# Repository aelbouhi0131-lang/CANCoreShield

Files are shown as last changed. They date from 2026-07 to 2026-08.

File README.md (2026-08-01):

<div align="center">

# CANCore Shield

A professional **Arduino UNO CAN-Bus Shield** designed in **Altium Designer**, featuring CAN communication, microSD storage, power management, and hardware improvements over existing open-source designs.










---

Designed by **Ayoub ELBOUHI**

Electrical Engineering & Embedded Systems Student

ENSA Marrakech

</div>

---

# Overview

CANCore Shield is a compact **Arduino UNO expansion board** developed for **CAN-Bus communication** and **embedded system applications**.

The project was inspired by existing open-hardware CAN shields (including the Seeed Studio CAN-BUS Shield) but redesigned from scratch with several improvements focused on:

- Hardware reliability
- Power management
- SD card compatibility
- PCB organization
- Ease of debugging
- Manufacturing readiness

The entire project was designed using **Altium Designer**, following professional PCB design practices and successfully verified with **0 Design Rule Check (DRC) errors**.

---

# Key Features

- Arduino UNO Shield Form Factor
- MCP2515 CAN Controller
- TJA1050 CAN Transceiver
- SPI microSD Card Interface
- Bidirectional Logic Level Translator
- Dedicated Power Management Circuit
- ON/OFF Power Switch
- Power & Status LEDs
- Optimized Ground Planes
- Two-Layer PCB
- STEP 3D Model Included
- Manufacturing Ready
- Fully DRC Verified

---

# Design Improvements

Unlike the reference open-source designs, this project introduces several hardware enhancements.

## Power Management

A dedicated **ON/OFF switch** allows complete control of the shield power without unplugging the Arduino board.

Benefits:

- Easier testing
- Faster debugging
- Better user experience

---

## Safer microSD Interface

A **unidirectional logic level translator** was added between the Arduino (5V) and the microSD card (3.3V).

Benefits:

- Protects the SD card
- Improves compatibility
- Reliable SPI communication
- Safe voltage conversion

---

## Visual Status Indicators

Dedicated LEDs provide immediate visual feedback regarding board operation.

Useful for:

- Power verification
- Debugging
- Development

---

## PCB Layout Optimization

The PCB was completely redesigned instead of copying an existing layout.

Improvements include:

- Cleaner routing
- Better component placement
- Optimized SPI routing
- Improved CAN signal organization
- Large continuous ground pours
- Easier maintenance

---

## Manufacturing Ready

The board has been fully verified using Altium Designer DRC.

Included manufacturing outputs:

- Gerber Files
- NC Drill Files
- STEP Mechanical Model

Ready for fabrication using:

- JLCPCB
- PCBWay
- Seeed Fusion
- Aisler

---

# PCB Preview

## Top Layer

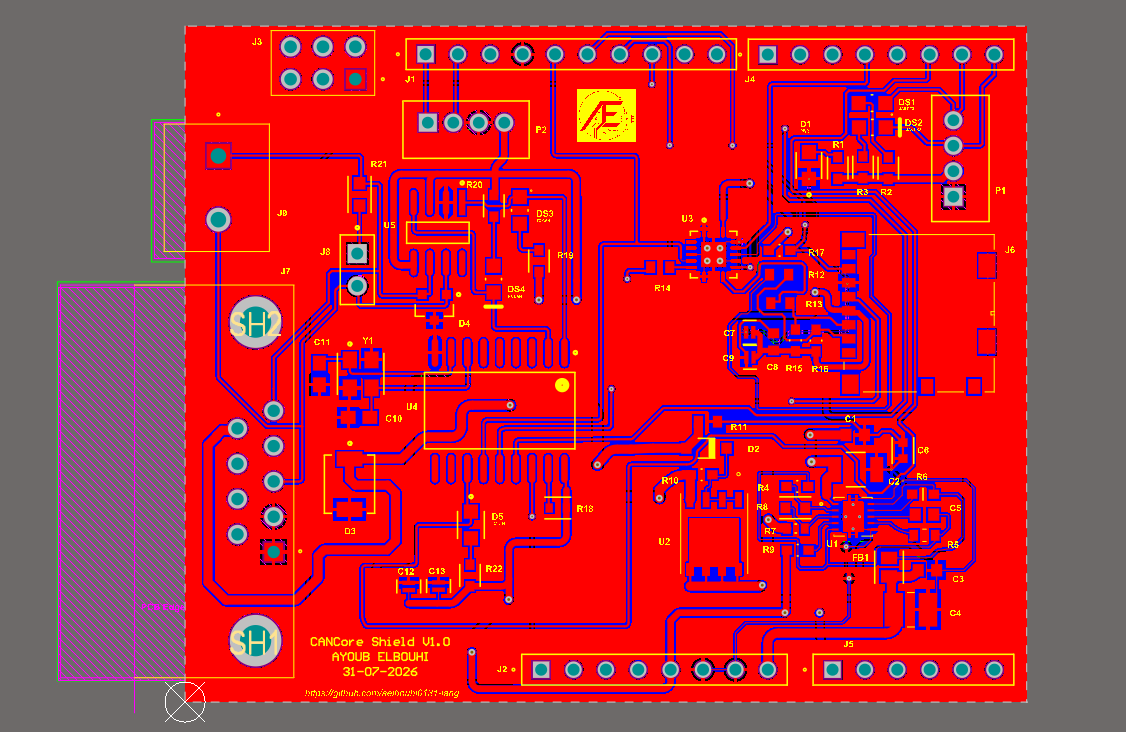
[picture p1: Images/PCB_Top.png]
PCB Top


---

## Bottom Layer

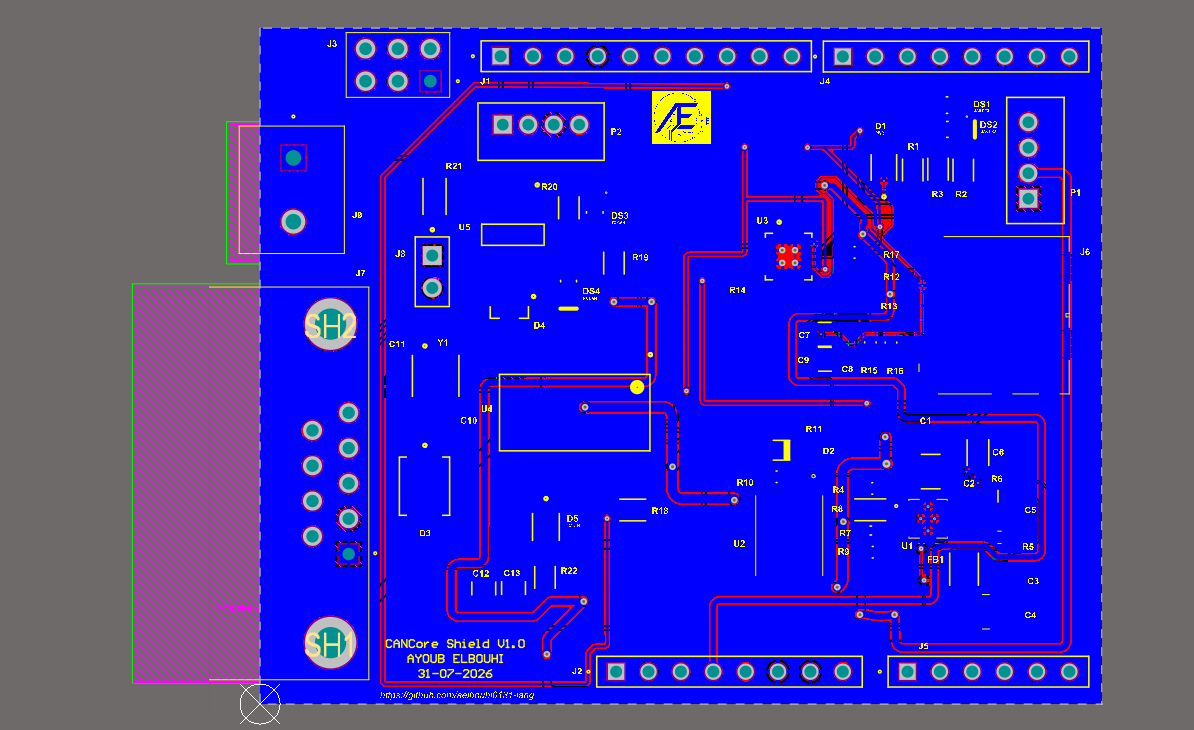
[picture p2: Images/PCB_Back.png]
PCB Bottom


---

## 3D View

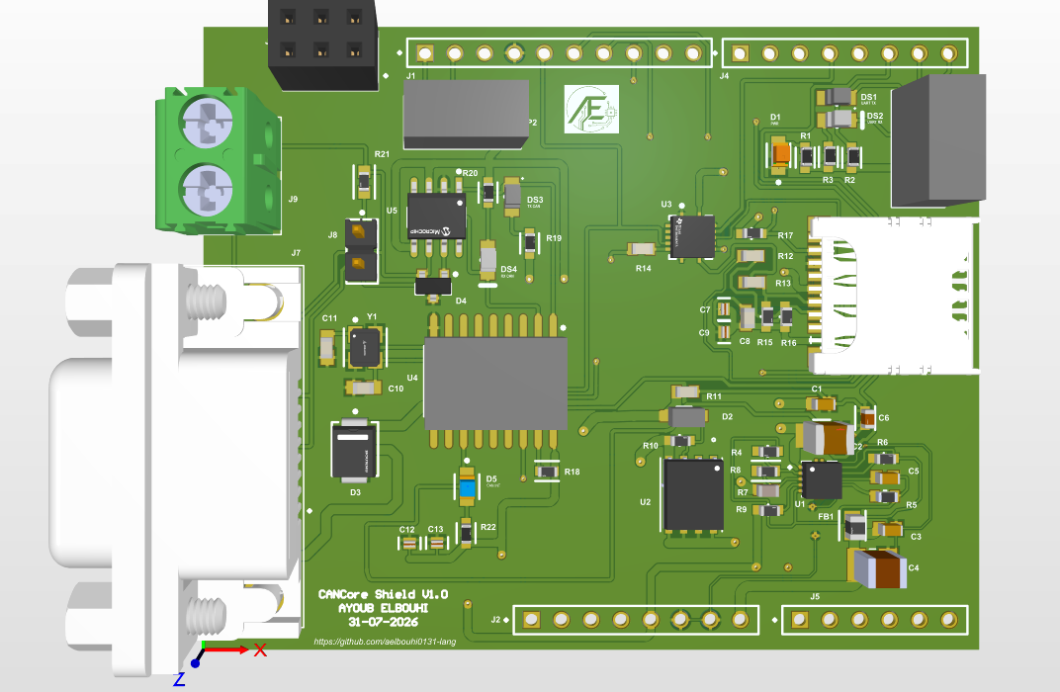
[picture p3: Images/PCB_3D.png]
PCB 3D


---

# Project Architecture

```
                       Arduino UNO
                            │
        ┌───────────────────┼────────────────────┐
        │                   │                    │
        ▼                   ▼                    ▼
   MCP2515 CAN         microSD Interface     Power Supply
   Controller          + Level Translator     + Switch
        │
        ▼
   TJA1050 CAN
   Transceiver
        │
        ▼
   CAN Bus Connector
```

---

# Repository Structure

```
CANCoreShield
│
├── Images
│   ├── PCB_3D.png
│   ├── PCB_Back.png
│   ├── PCB_Top.png
│
├── Manufacturing
│   └── CANCoreShield_Gerbers.zip
│
├── Schematics
│   ├── TOP_Sheet.SchDoc
│   ├── 01_Arduino_IO.SchDoc
│   ├── 02_CAN.SchDoc
│   ├── 03_SD_Card.SchDoc
│   └── 04_Power.SchDoc
│
├── CANCore Shield.PcbDoc
├── CANCore Shield.PrjPcb
├── CANCore Shield.OutJob
├── CANCore Shield 3D View.step
└── CANCore Shield.pdf
```

---

# Schematics

The hardware is divided into four functional hierarchical sheets:

| Sheet | Description |
|---|---|
| 01 | Arduino Interface |
| 02 | CAN Communication |
| 03 | microSD Interface |
| 04 | Power Supply |

The complete PDF schematic is included in:

```
CANCore Shield.pdf
```

---

# PCB Design

Designed using **Altium Designer**.

Main design stages:

- Schematic Capture
- Component Placement
- Manual Routing
- Copper Pours
- 3D Verification
- Design Rule Check

Final Status

**0 DRC Errors**

---

# Manufacturing Files

Located in:

```
Manufacturing/
```

Included:

- Gerbers
- NC Drill
- Ready for fabrication

---

# 3D Model

A complete STEP model is provided for mechanical integration.

```
CANCore Shield 3D View.step
```

---

# Software

- Altium Designer
- CAMtastic
- Design Rule Check (DRC)

---

# Future Improvements

Possible future versions may include:

- CAN FD Support
- ESD Protection
- Reverse Polarity Protection
- Power Monitoring
- Additional Status LEDs
- Isolated CAN Interface

---

# Acknowledgments

This project was inspired by several open-hardware CAN shield designs, particularly the **Seeed Studio CAN-BUS Shield**, while introducing multiple hardware and PCB improvements tailored for educational and embedded system applications.

---

# Author

**Ayoub ELBOUHI**

Electrical Engineering & Embedded Systems Student

ENSA Marrakech

GitHub:

https://github.com/aelbouhi0131

---

If you found this project useful, consider giving it a ⭐ on GitHub.

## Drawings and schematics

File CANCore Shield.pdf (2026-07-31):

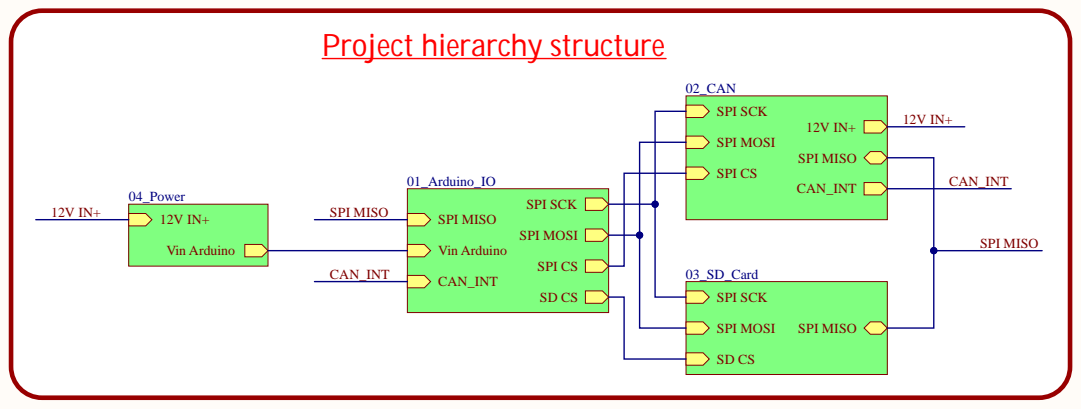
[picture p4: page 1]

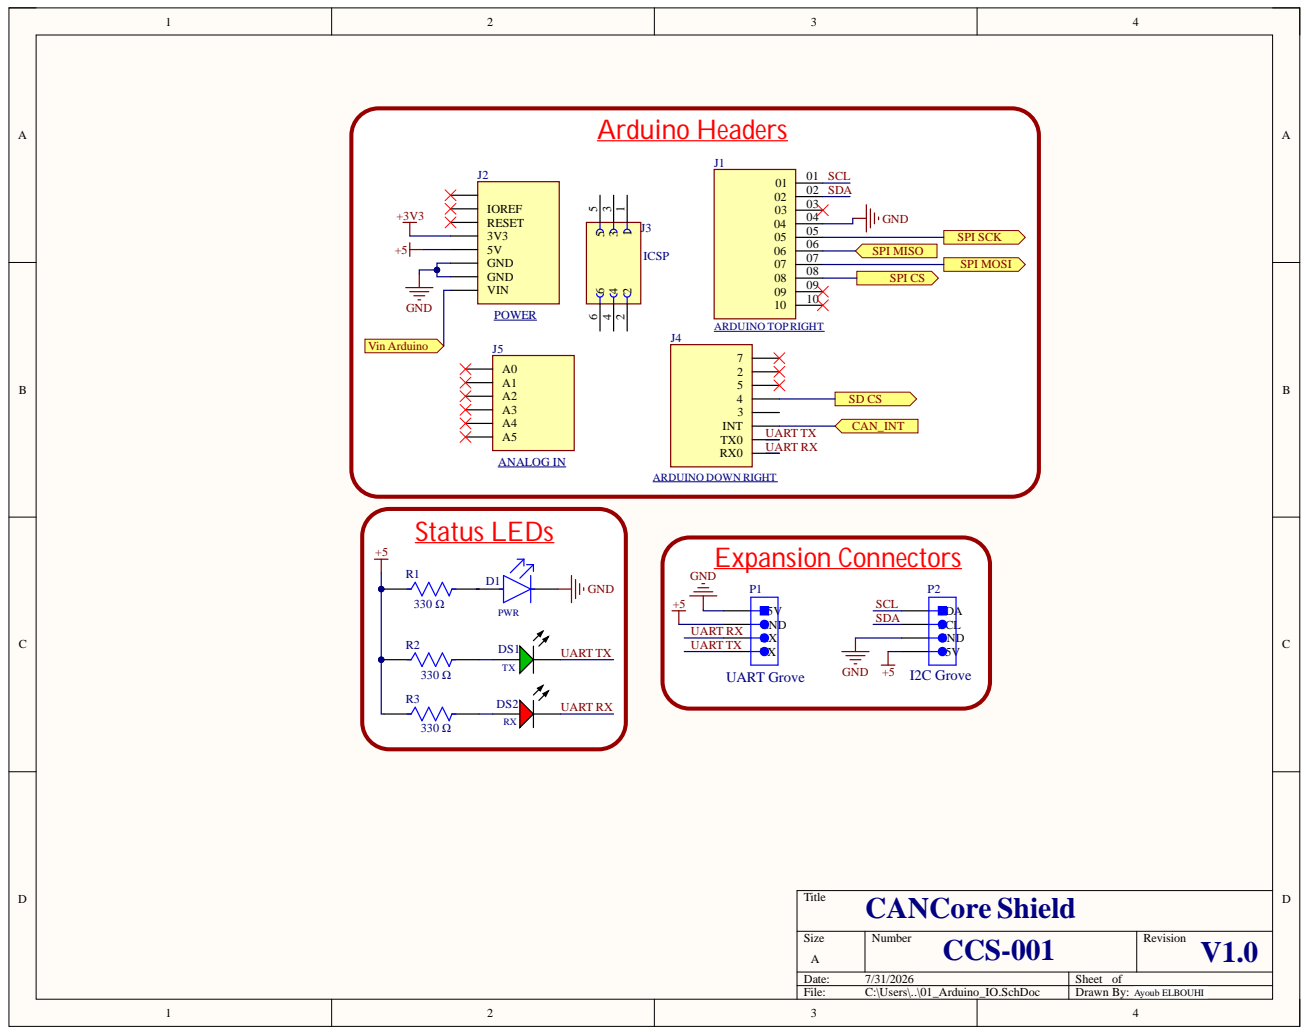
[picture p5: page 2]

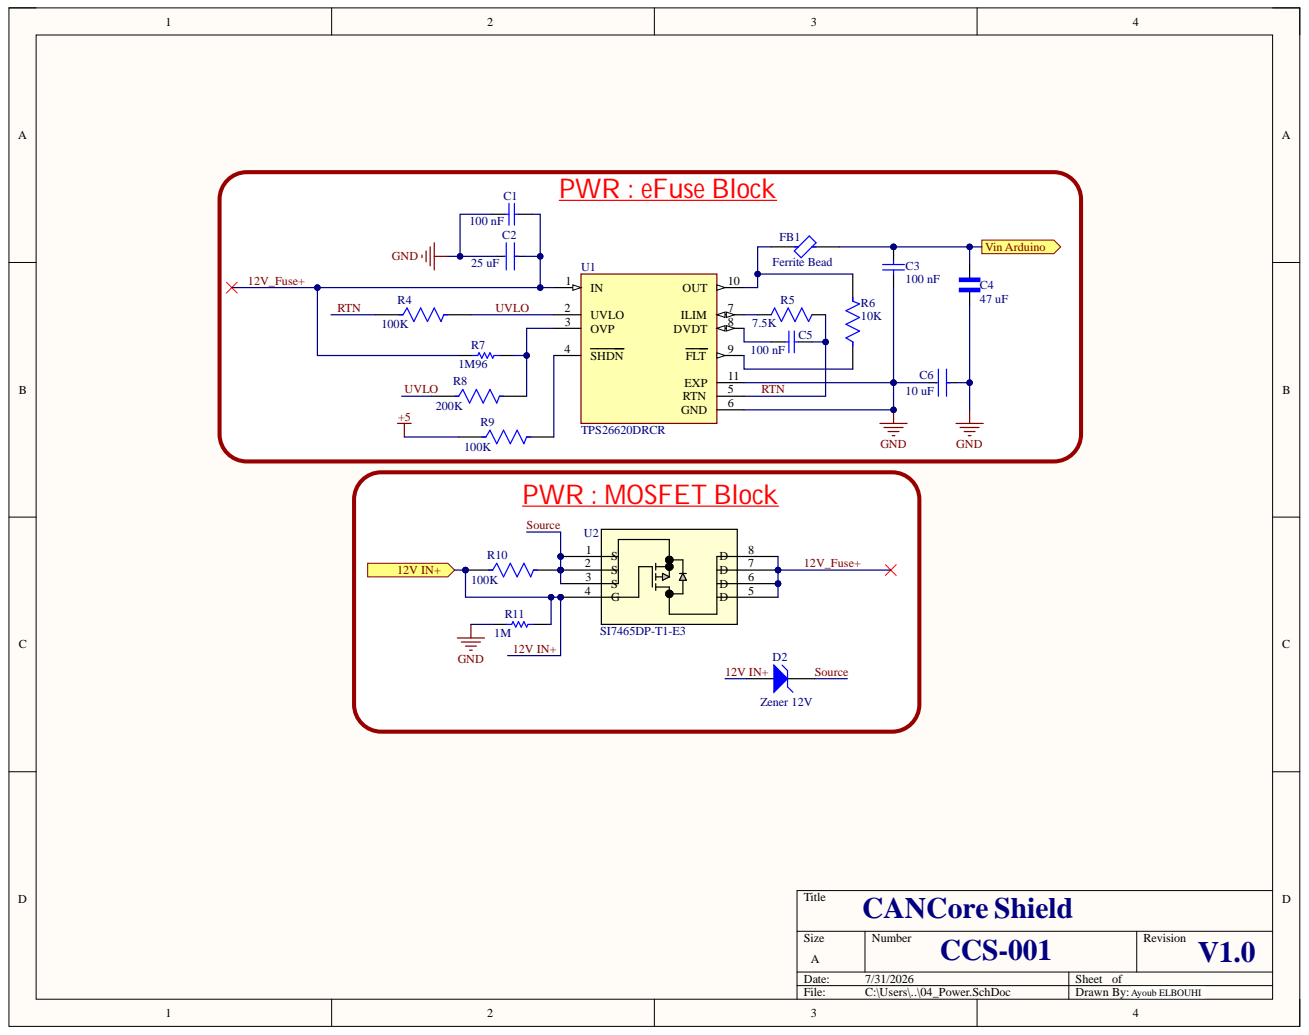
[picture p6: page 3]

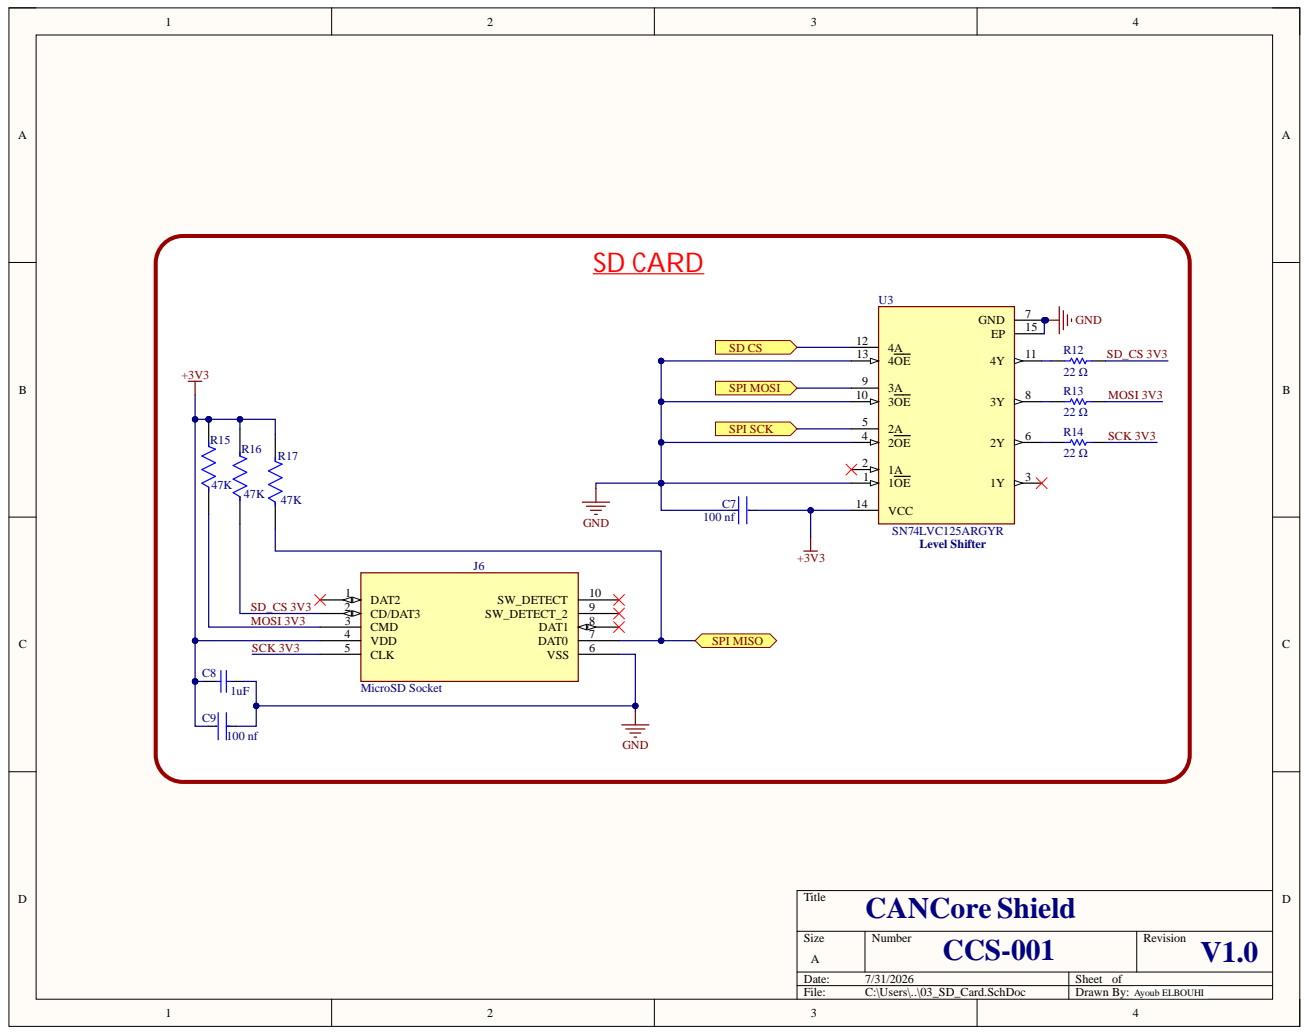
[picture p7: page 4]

VCC 14

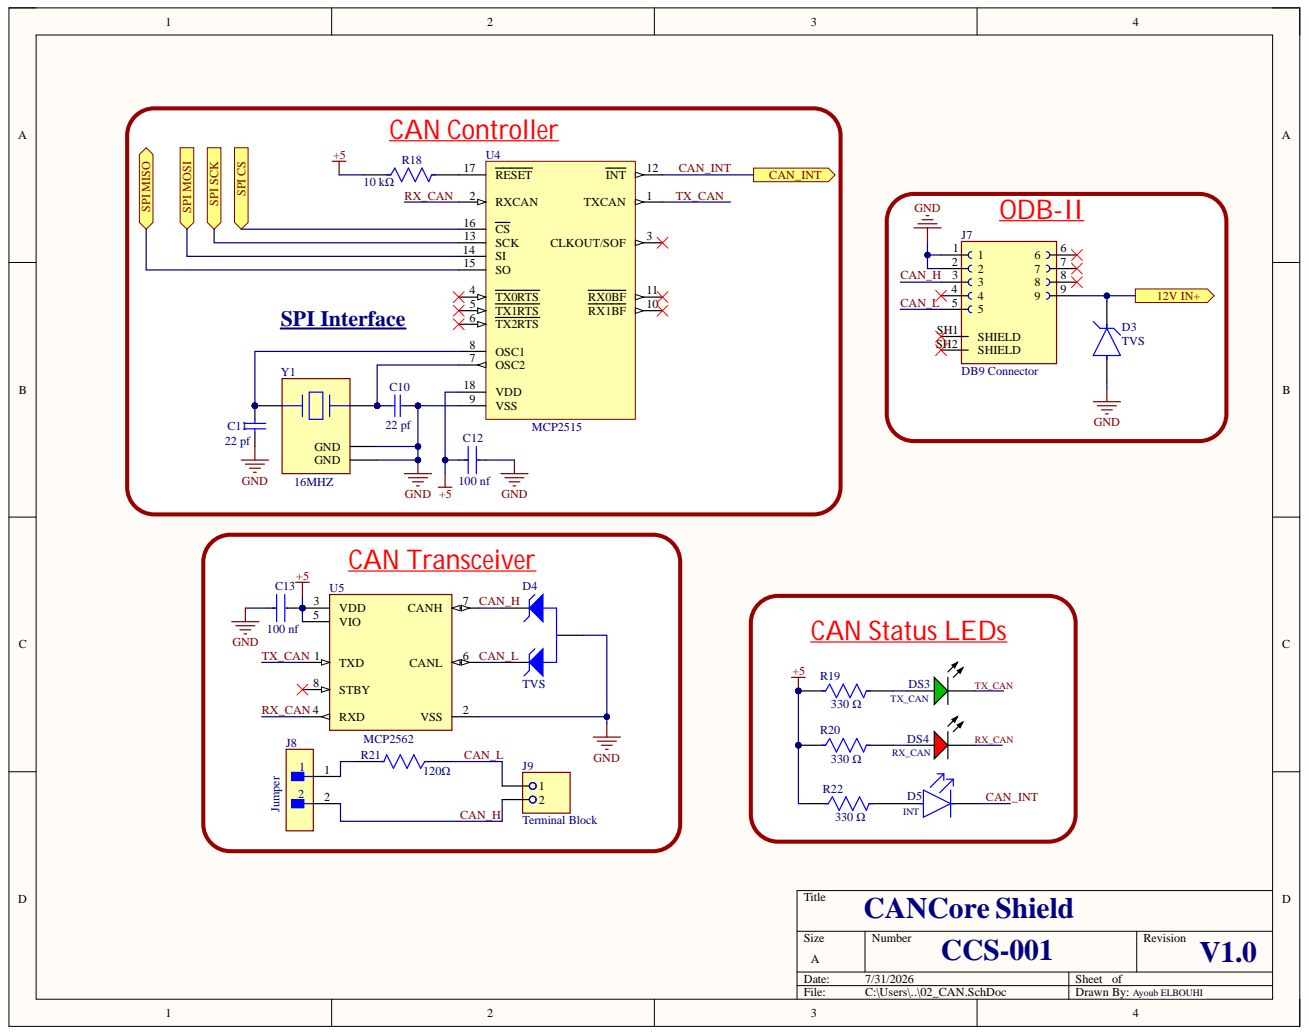
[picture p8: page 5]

C10 | | VDD 18

GND | 22 pf

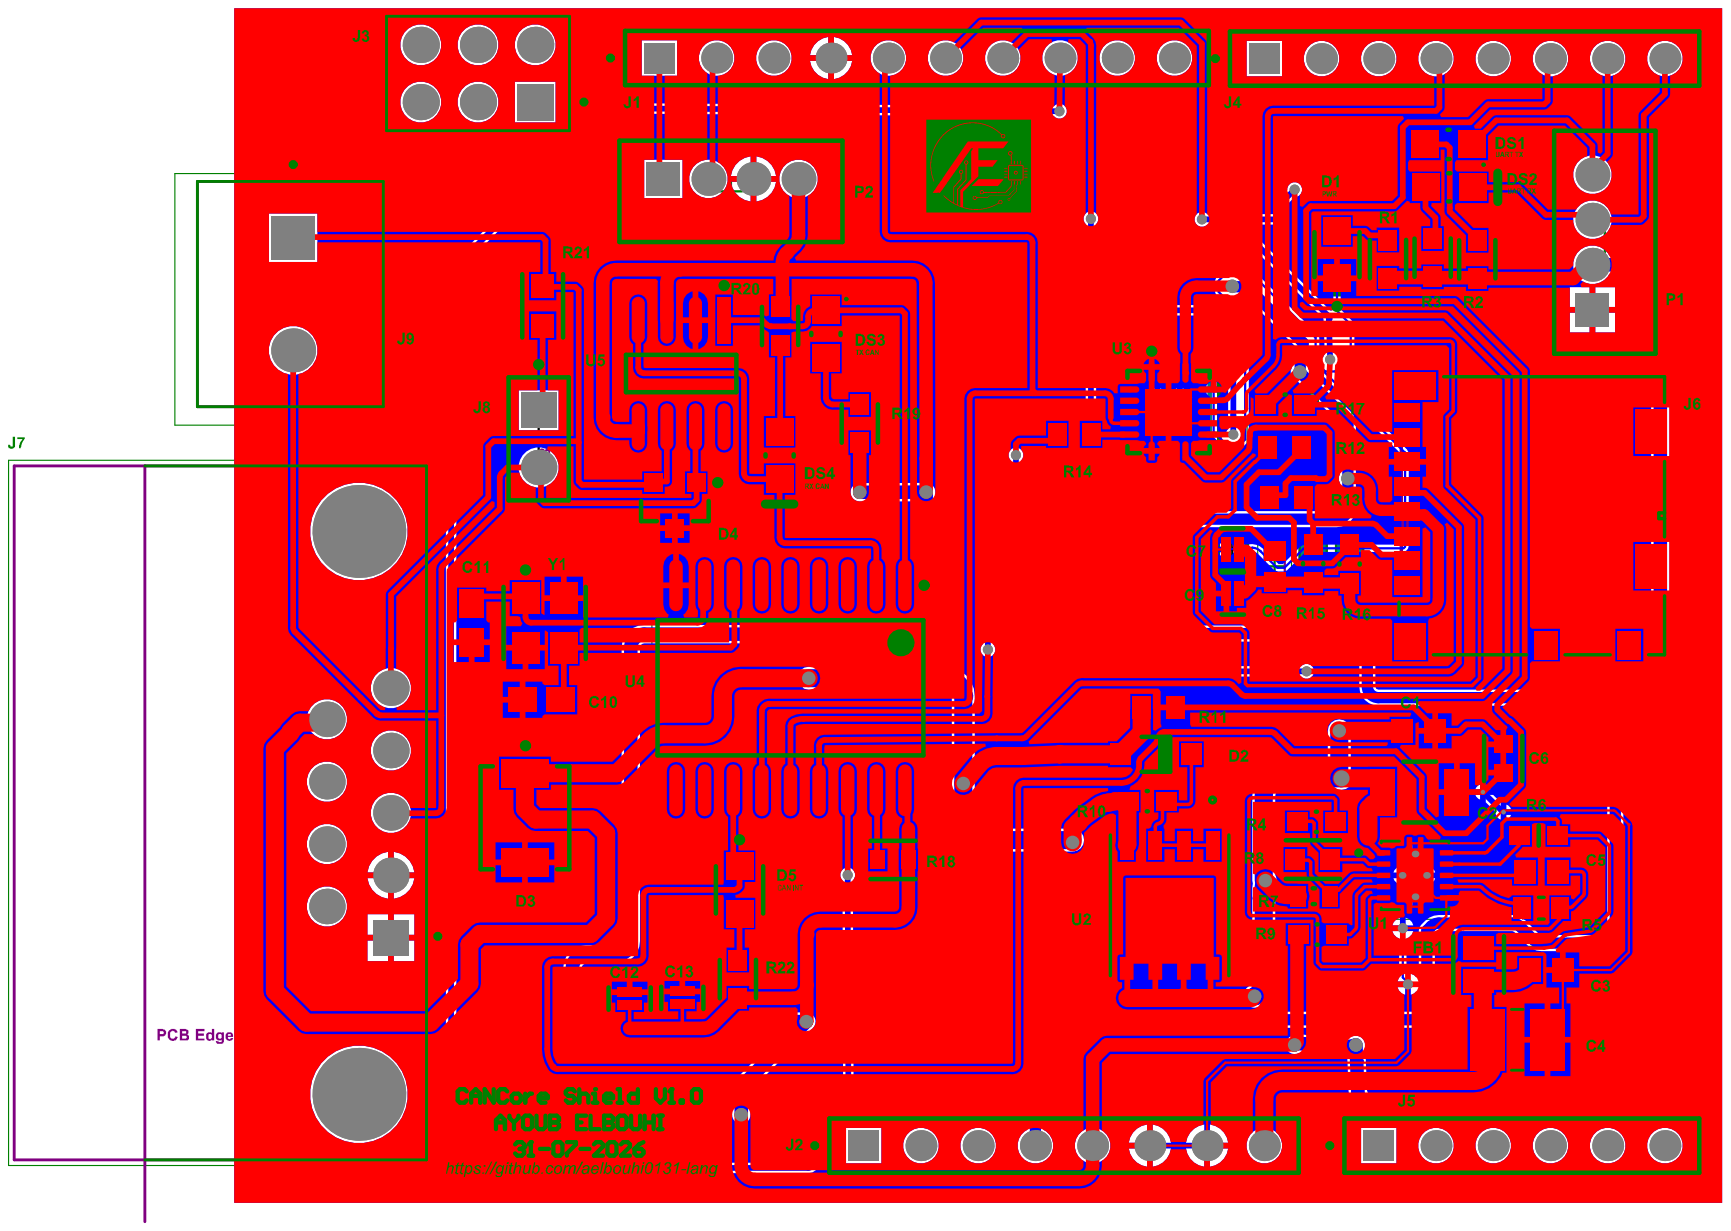
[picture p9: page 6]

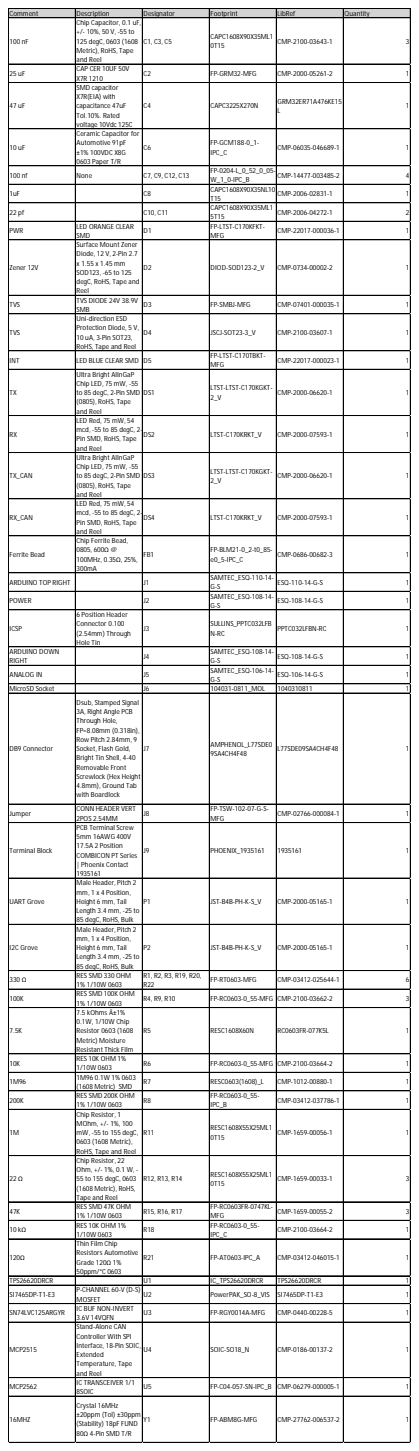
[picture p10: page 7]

25 uF | CAP CER 10UF 50V X7R 1210 | C2 | FP-GRM32-MFG | CMP-2000-05261-2 | 1

47 uF | SMD capacitor X7R(EIA) with capacitance 47uF Tol.10%. Rated voltage 10Vdc 125C | C4 | CAPC3225X270N | GRM32ER71A476KE15 L | 1

10 uF | Ceramic Capacitor for Automotive 91pF ±1% 100VDC X8G 0603 Paper T/R | C6 | FP-GCM188-0_1-IPC_C | CMP-06035-046689-1 | 1

100 nf | None | C7, C9, C12, C13 | FP-0204-L_0_52_0_05-W_1_0-IPC_B | CMP-14477-003485-2 | 4

1uF | | C8 | CAPC1608X90X35NL10 T15 | CMP-2006-02831-1 | 1

22 pf | | C10, C11 | CAPC1608X90X35ML1 5T15 | CMP-2006-04272-1 | 2

PWR | LED ORANGE CLEAR SMD | D1 | FP-LTST-C170KFKT-MFG | CMP-22017-000036-1 | 1

Zener 12V | Surface Mount Zener Diode, 12 V, 2-Pin 2.7 x 1.55 x 1.45 mm SOD123, -65 to 125 degC, RoHS, Tape and Reel | D2 | DIOD-SOD123-2_V | CMP-0734-00002-2 | 1

TVS | TVS DIODE 24V 38.9V SMB | D3 | FP-SMBJ-MFG | CMP-07401-000035-1 | 1

TVS | Uni-direction ESD Protection Diode, 5 V, 10 uA, 3-Pin SOT23, RoHS, Tape and Reel | D4 | JSCJ-SOT23-3_V | CMP-2100-03607-1 | 1

INT | LED BLUE CLEAR SMD | D5 | FP-LTST-C170TBKT-MFG | CMP-22017-000023-1 | 1

TX | Ultra Bright AlInGaP Chip LED, 75 mW, -55 to 85 degC, 2-Pin SMD (0805), RoHS, Tape and Reel | DS1 | LTST-LTST-C170KGKT-2_V | CMP-2000-06620-1 | 1

RX | LED Red, 75 mW, 54 mcd, -55 to 85 degC, 2-Pin SMD, RoHS, Tape and Reel | DS2 | LTST-C170KRKT_V | CMP-2000-07593-1 | 1

TX_CAN | Ultra Bright AlInGaP Chip LED, 75 mW, -55 to 85 degC, 2-Pin SMD (0805), RoHS, Tape and Reel | DS3 | LTST-LTST-C170KGKT-2_V | CMP-2000-06620-1 | 1

RX_CAN | LED Red, 75 mW, 54 mcd, -55 to 85 degC, 2-Pin SMD, RoHS, Tape and Reel | DS4 | LTST-C170KRKT_V | CMP-2000-07593-1 | 1

Ferrite Bead | Chip Ferrite Bead, 0805, 600Ω @ 100MHz, 0.35Ω, 25%, 300mA | FB1 | FP-BLM21-0_2-t0_85-e0_5-IPC_C | CMP-0686-00682-3 | 1

ARDUINO TOP RIGHT | | J1 | SAMTEC_ESQ-110-14-G-S | ESQ-110-14-G-S | 1

POWER | | J2 | SAMTEC_ESQ-108-14-G-S | ESQ-108-14-G-S | 1

ICSP | 6 Position Header Connector 0.100 (2.54mm) Through Hole Tin | J3 | SULLINS_PPTC032LFB N-RC | PPTC032LFBN-RC | 1

ARDUINO DOWN RIGHT | | J4 | SAMTEC_ESQ-108-14-G-S | ESQ-108-14-G-S | 1

ANALOG IN | | J5 | SAMTEC_ESQ-106-14-G-S | ESQ-106-14-G-S | 1

MicroSD Socket | | J6 | 104031-0811_MOL | 1040310811 | 1
DB9 Connector | Dsub, Stamped Signal 3A, Right Angle PCB Through Hole, FP=8.08mm (0.318in), Row Pitch 2.84mm, 9 Socket, Flash Gold, Bright Tin Shell, 4-40 Removable Front Screwlock (Hex Height 4.8mm), Ground Tab with Boardlock | J7 | AMPHENOL_L77SDE0 9SA4CH4F48 | L77SDE09SA4CH4F48 | 1

Jumper | CONN HEADER VERT 2POS 2.54MM | J8 | FP-TSW-102-07-G-S-MFG | CMP-02766-000084-1 | 1

Terminal Block | PCB Terminal Screw 5mm 16AWG 400V 17.5A 2 Position COMBICON PT Series | Phoenix Contact 1935161 | J9 | PHOENIX_1935161 | 1935161 | 1

UART Grove | Male Header, Pitch 2 mm, 1 x 4 Position, Height 6 mm, Tail Length 3.4 mm, -25 to 85 degC, RoHS, Bulk | P1 | JST-B4B-PH-K-S_V | CMP-2000-05165-1 | 1

I2C Grove | Male Header, Pitch 2 mm, 1 x 4 Position, Height 6 mm, Tail Length 3.4 mm, -25 to 85 degC, RoHS, Bulk | P2 | JST-B4B-PH-K-S_V | CMP-2000-05165-1 | 1

330 Ω | RES SMD 330 OHM 1% 1/10W 0603 | R1, R2, R3, R19, R20, R22 | FP-RT0603-MFG | CMP-03412-025644-1 | 6

100K | RES SMD 100K OHM 1% 1/10W 0603 | R4, R9, R10 | FP-RC0603-0_55-MFG | CMP-2100-03662-2 | 3

7.5K | 7.5 kOhms Â±1% 0.1W, 1/10W Chip Resistor 0603 (1608 Metric) Moisture Resistant Thick Film | R5 | RESC1608X60N | RC0603FR-077K5L | 1

10K | RES 10K OHM 1% 1/10W 0603 | R6 | FP-RC0603-0_55-MFG | CMP-2100-03664-2 | 1

1M96 | 1M96 0.1W 1% 0603 (1608 Metric) SMD | R7 | RESC0603(1608)_L | CMP-1012-00880-1 | 1

200K | RES SMD 200K OHM 1% 1/10W 0603 | R8 | FP-RC0603-0_55-IPC_B | CMP-03412-037786-1 | 1

1M | Chip Resistor, 1 MOhm, +/- 1%, 100 mW, -55 to 155 degC, 0603 (1608 Metric), RoHS, Tape and Reel | R11 | RESC1608X55X25ML1 0T15 | CMP-1659-00056-1 | 1

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
